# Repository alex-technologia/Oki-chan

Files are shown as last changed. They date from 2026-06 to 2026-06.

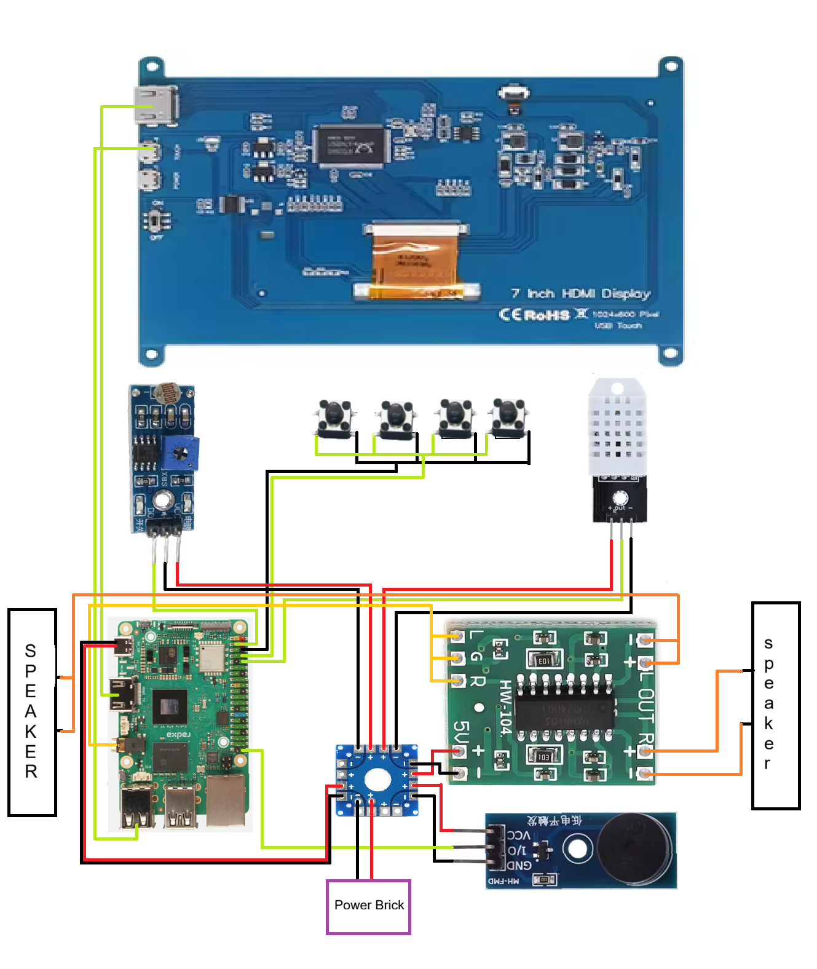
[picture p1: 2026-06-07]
Schematics/Wiring schematic.png

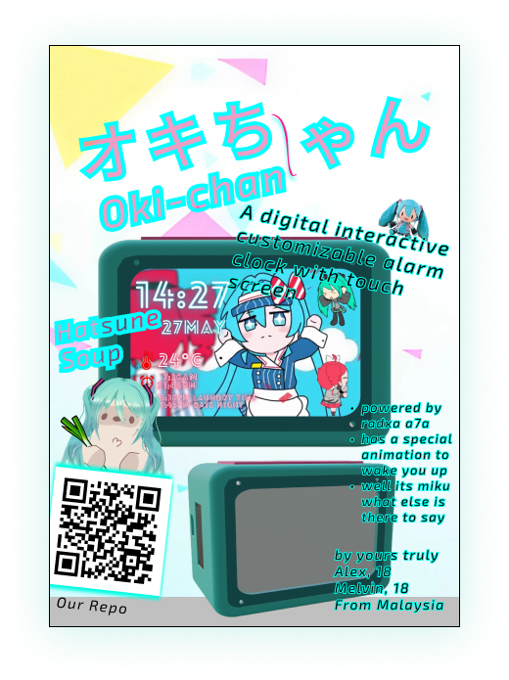
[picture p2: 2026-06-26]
assets/Okichan Zine.png

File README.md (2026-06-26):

<p align="center">
  
</p>

<table>
<tr>
<td width="40%">

Okichan Zine

</td>

<td width="60%">

<h3>Oki-chan (Okiru = wake up / Ooki = big)</h3>

A digital interactive customizable alarm clock with a touch screen. Normal alarm clocks are boring—animate whatever you want and put it on the display. I'm probably going to use an anime character, but it's completely customizable on the software side.

This alarm clock runs Linux/Android, so you can run almost anything you want on it—even Doom.

We created software that functions as both an alarm clock and a character display. The default character is
giphy,
but you can replace it with whoever you like. (work in progress)

We made this project to prove that waking up doesn't have to be frustrating or painful while still giving users complete freedom to customize their experience. ps. I hate waking up so I'm trying to make waking up fun!

It is super simple to use, just install the android firmware from radxa's official website and you're ready to go! It's touchscreen so u can use it like any mobile gadget but in the form of an alarm clock.

</td>
</tr>
</table>

## Onshape link 
[[https://cad.onshape.com/documents/88c036c3c5f450a3cafc0f79/w/50fab2545bc89d9e2dabb88b/e/1d1f4fe3c64da217baa0164f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](https://cad.onshape.com/documents/4e082104674894d5913c4831/w/89eadd96b42d6e928645da0e/e/e63404fe947eb1d5f2b5a918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)](https://cad.onshape.com/documents/c2196d859270cbefb2446175/w/1e22324b9374e77f752ec0d0/e/32ebcde7a799d4cd3d4bf5ae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)

## 3D Model
  <tr>
    <td>
      
    </td>
    <td>
      
    </td>
  </tr>
  <tr>
    <td>
      
    </td>
    <td>
      
    </td>
  </tr>
</table>

## Wiring Diagram
Wiring schematic

🟥RED = +wire
⬛BLACK = -wire
🟩GREEN = Data wire
🟧ORANGE = Audio+/-
🟨YELLOW = AUX Wire

## BOM


## Flashing Firmware
Android
Compatible with microSD cards, eMMC modules, and UFS modules.

<table>
  <tr>
    <td colspan="2">

## 1. Download Firmware

### Radxa Cubie A7A Android 13 Images

[Radxa Cubie A7A Android 13 **20250814**](https://github.com/radxa/allwinner-android-manifests/releases/download/A733-Android13-20250814/a733_android13_radxa_a7a_20250814_uart0.zip): for Cubie A7A with **AC101** audio codec

[Radxa Cubie A7A Android 13 **20260206**](https://github.com/radxa/allwinner-android-manifests/releases/download/A733-Android13-20260205/a733_android13_radxa_a7a_20260206_uart0.zip): for Cubie A7A with **AC101B** audio codec

  </tr>

  <tr>
    <td width="50%" valign="top">

## 2A. SD Card Flashing

### SD Card Boot Disk Creation Tool

- [PhoenixCard V4.3.2](https://dl.radxa.com/tools/windows/PhoenixCard_V4.3.2_20250331_1604_Release.zip)

1. Insert SD card into PC.
2. Open PhoenixCard.
3. Select the firmware image from Step 1.
4. Create the bootable SD card.
5. Insert SD card into the Radxa A7A and power on.

    </td>

    <td width="50%" valign="top">

## 2B. USB Flashing

### System Flashing Tools

- [PhoenixSuit](https://dl.radxa.com/tools/windows/PhoenixSuit_V2.0.4.zip) (Windows)
- [LiveSuit](https://dl.radxa.com/tools/linux/LiveSuit_Linux_V3.0.8.zip) (Linux)

1. Unplug power and USB cables from the Radxa A7A.
2. Press and hold the **UBOOT** button.
3. Connect the Radxa A7A to the PC using a USB cable.
4. Release the **UBOOT** button.
5. Open Device Manager and verify the board appears under USB Devices.
6. Open PhoenixSuit/LiveSuit and select the firmware image from Step 1.
7. Choose **Full Flash**.
8. Wait until **"Firmware flashed successfully"** is displayed.
9. The board is now ready to use.
  </tr>
</table>

Official Radxa A7a Android Docs [HERE](https://docs.radxa.com/en/cubie/a7a/other-system/android) 

(Debian&Tina not used in this project), it's available by following [Radxa official docs](https://docs.radxa.com/en/cubie/a7a/download) if you want.

## **Apps**
Oki-chan is not limited by our app, thus you can use any other app you want that is android (side-loading required).

As for our app, it will be running as [Oki-chan Webui.html]() file and is still in devolopment. 

## Preview
What could be possible (we haven't made the software for it yet)  

https://github.com/user-attachments/assets/e6b8e22e-ab00-47f7-8dbc-2a04c18cb579

## Zine 
Untitled(22)

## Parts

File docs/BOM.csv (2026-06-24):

Item | Purpose | Source | Price (Malaysia Currency) | Price (usd) | Quantity | Link
Radxa cubie a7a | Main computer | Aliexpress | 153 | 38.62 | 1 | https://www.aliexpress.com/item/1005009735747676.html
Micro Digital Amplier Board | For the audio amplifier speaker | Aliexpress | 2.09 | 0.53 | 1 | https://a.aliexpress.com/_c3usjmxJ
Audio amplifier board plastic speaker | As the speaker for the alarm | TaoBao | 2.90 | 0.73 | 2 | https://click.world.taobao.com/_b.bbuoO7
Passive Buzzer Module | As the vibration module for the alarm vibration | Aliexpress | 4.00 | 1.01 | 1 | https://www.aliexpress.com/item/1005010218492946.html
Screen With Touch Film (7 inch) | As the screen that shows the animation | TaoBao | 106.79 | 26.95 | 1 | https://click.world.taobao.com/_b.hbuo7h
Tactile switch button | As the snooze button | TaoBao | 1.53 | 0.39 | 4 | https://click.world.taobao.com/_b.4bupYW
Power Supply Adapter 5V 6A | Changes alternating current to direct current | Aliexpress | 21.58 | 5.45 | 1 | https://www.aliexpress.com/item/1005005622817698.html
Power Distribution Board | Distribute the current to other parts | Aliexpress | 17.94 | 4.53 | 1 | https://www.aliexpress.com/item/1005001835785033.html
M4 and M2.5 hex screws | Hold components together | Alixpress | ±10 | ±2.53 | 31 | https://www.aliexpress.com/item/1005006904738286.html
Wires | Allow current to be transferred to the parts | Owned | ±2.00 | ±0.50 | - | -
3D Printer | Used to print out the model | Owned | - | - | - | -
3D Printer FIlament PLA+ | Filament for 3D printer | owned | ±30.00 | ±7.24 | - | -
Solder | Used to solder wire and electronic components together | owned | - | - | - | -
Soldering stick | Used to melt solder | owned | ±10.00 | ±2.41 | - | -
TOTAL COST | - | (Not including things we owned) | ±320.31 | ±77.29 | - | -

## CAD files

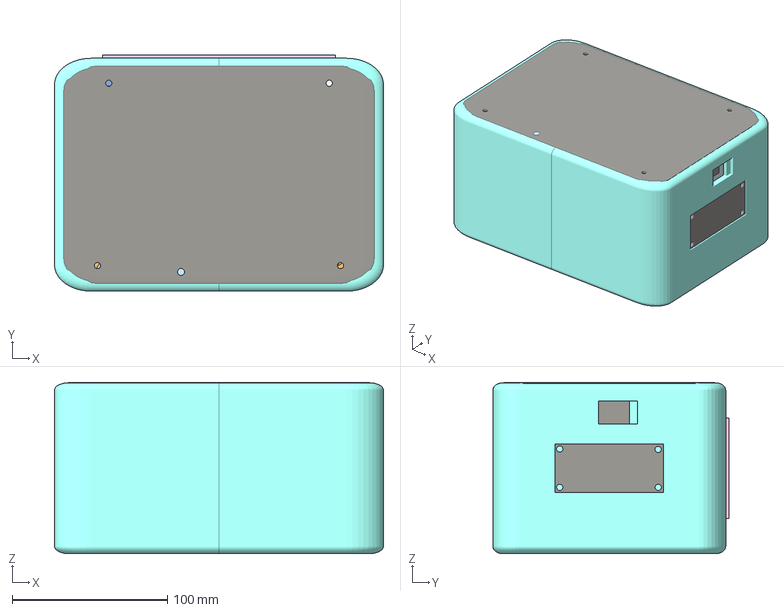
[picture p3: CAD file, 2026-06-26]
Schematics/okichanv5(1).step
211.8 x 152.2 x 110.3 mm

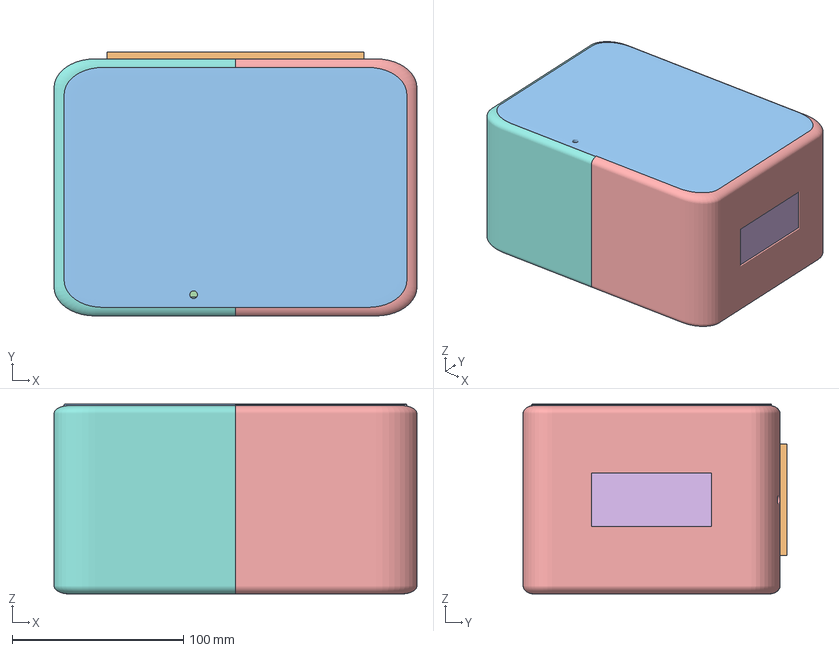
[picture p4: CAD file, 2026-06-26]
Schematics/oki.FCStd
211.8 x 154.0 x 110.9 mm
switch.004 (1)
speaker.001 (1)
buck converter holder
speaker.001
vibrator holder bottom
back cover holder
Case.002 (3)
light sensor
back cover holder (4)
Case.002 (7)
switch (1)
back cover holder (2)
Case.002 (4)
switch
back cover holder (1)
Case.002
switch.001 (1)
sbc holder.002
Case.002 (5)
switch.001
amp holder top (7)
switch.003 (1)
amp holder bottom
amp holder top (1)
back cover holder (3)
Case.002 (1)
sbc
switch.003
switch.004
amp holder top (6)
buck converter
Case.002 (6)
screen (1)
amp holder top (2)
amp holder top
switch.002
Case.002 (2)
sbc holder.001
amp holder top (4)
switch.002 (1)
screen
sbc holder
speaker (1)
amp holder top (5)
screen holder (4)
PDB
speaker
amp holder top (3)
screen holder
powerjack
vibrator holder top
Case.002 (6)001
screen holder (3)
screen holder (1)
screen holder (2)

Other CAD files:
Schematics/okichanv5 renderv7 .blend
Schematics/okichanv5.blend
docs/3D Model.blend

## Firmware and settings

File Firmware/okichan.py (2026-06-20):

import os
import sys
import time
import threading
import subprocess
import webview

# Attempt to load native Linux I/O drivers
try:
    import gpiod
    HARDWARE_AVAILABLE = True
except ImportError:
    HARDWARE_AVAILABLE = False
    print("[WARN] gpiod library missing. Initializing in desktop emulation mode.")

# ==========================================
# HARDWARE CORE PIN CONFIGURATION
# ==========================================
GPIO_CHIP_NAME = "gpiochip4"
PIN_BUTTON_1 = 10   # Cycle App Pages
PIN_BUTTON_2 = 11   # Trigger Buzzer Pulse
PIN_BUTTON_3 = 12   # System Volume Up
PIN_BUTTON_4 = 13   # System Volume Down
PIN_LIGHT_IN = 14   # Digital Input from Photoresistor Module
PIN_BUZZER_OUT = 15 # Digital Output to Piezo Buzzer

SOUND_FILE_PATH = "/usr/share/sounds/alsa/Front_Center.wav"

class WebAppHardwareBridge:
    """API Object exposed directly to JavaScript inside the WebView window container."""
    def __init__(self):
        self.window = None
        self.volume_level = 70
        self.running = True
        self.init_gpio_lines()

    def init_gpio_lines(self):
        if not HARDWARE_AVAILABLE:
            return
        try:
            self.chip = gpiod.Chip(GPIO_CHIP_NAME)
            
            # Map out hardware inputs with active-low safety bounds
            self.btn1 = self.chip.get_line(PIN_BUTTON_1); self.btn1.request(consumer="WebHub", type=gpiod.LINE_REQ_DIR_IN)
            self.btn2 = self.chip.get_line(PIN_BUTTON_2); self.btn2.request(consumer="WebHub", type=gpiod.LINE_REQ_DIR_IN)
            self.btn3 = self.chip.get_line(PIN_BUTTON_3); self.btn3.request(consumer="WebHub", type=gpiod.LINE_REQ_DIR_IN)
            self.btn4 = self.chip.get_line(PIN_BUTTON_4); self.btn4.request(consumer="WebHub", type=gpiod.LINE_REQ_DIR_IN)
            self.light_sensor = self.chip.get_line(PIN_LIGHT_IN); self.light_sensor.request(consumer="WebHub", type=gpiod.LINE_REQ_DIR_IN)
            
            # Map out output lines
            self.buzzer = self.chip.get_line(PIN_BUZZER_OUT); self.buzzer.request(consumer="WebHub", type=gpiod.LINE_REQ_DIR_OUT, default_vals=[0])
        except Exception as err:
            print(f"[GPIO Initialization Failure]: {err}")

    # --- Methods triggered directly from user interface clicks inside the Web UI ---
    def play_audio_alert(self):
        """Fired when UI Audio buttons are clicked."""
        if os.path.exists(SOUND_FILE_PATH):
            subprocess.run(["aplay", SOUND_FILE_PATH], stdout=subprocess.DEVNULL, stderr=subprocess.DEVNULL)
        return {"status": "success"}

    def pulse_hardware_buzzer(self):
        """Fired when UI Test Buzzer buttons are clicked."""
        def run_pulse():
            if HARDWARE_AVAILABLE:
                self.buzzer.set_value(1)
                time.sleep(0.15)
                self.buzzer.set_value(0)
            else:
                print("[EMULATION] *Buzzer Beep*")
        threading.Thread(target=run_pulse, daemon=True).start()
        return {"status": "activated"}

    def change_system_volume(self, target_direction):
        if target_direction == "up" and self.volume_level < 100:
            self.volume_level += 5
        elif target_direction == "down" and self.volume_level > 0:
            self.volume_level -= 5
        subprocess.run(["amixer", "sset", "Master", f"{self.volume_level}%"], stdout=subprocess.DEVNULL, stderr=subprocess.DEVNULL)
        return self.volume_level

    # --- Background Loop pushing data back into the Web DOM ---
    def start_hardware_polling(self):
        """Monitors input lines and executes javascript strings inside the runtime window context."""
        current_page_idx = 0
        pages_list = ["page-main-hub", "page-alarms", "page-tasks"]
        dht_ticks = 0

        while self.running:
            if HARDWARE_AVAILABLE:
                try:
                    # 1. Hardware Buttons mapped directly to Application Navigation Events
                    if self.btn1.get_value() == 0:  # Page Cycle Switch Button
                        current_page_idx = (current_page_idx + 1) % len(pages_list)
                        self.window.evaluate_js(f"switchPage('{pages_list[current_page_idx]}')")
                        time.sleep(0.3)

                    if self.btn2.get_value() == 0:  # Physical Trigger for the Buzzer
                        self.pulse_hardware_buzzer()
                        time.sleep(0.3)

                    if self.btn3.get_value() == 0:  # Volume Up Pin
                        self.change_system_volume("up")
                        time.sleep(0.15)

                    if self.btn4.get_value() == 0:  # Volume Down Pin
                        self.change_system_volume("down")
                        time.sleep(0.15)

                    # 2. Update Webpage UI based on Photoresistor state
                    # Automatically dismisses screensaver overlay if light status changes significantly
                    if self.light_sensor.get_value() == 0:
                        self.window.evaluate_js("userActivityRegistered();")

                    # 3. Read Temp/Humidity Data from SysFS nodes into Web Screensaver View
                    dht_ticks += 1
                    if dht_ticks >= 20: # Query hardware roughly every 2 seconds
                        temp_path = "/sys/bus/iio/devices/iio:device0/in_temp_input"
                        if os.path.exists(temp_path):
                            with open(temp_path, "r") as f:
                                current_temp = float(f.read().strip()) / 1000.0
                            # Dynamically modifies the target text node within the screensaver stack layout
                            js_update = f"document.querySelector('#idle-screensaver .saver-widget-row span').textContent = '{current_temp:.1f}°C';"
                            self.window.evaluate_js(js_update)
                        dht_ticks = 0

                except Exception as loop_error:
                    print(f"Polling loop hiccup: {loop_error}")

            time.sleep(0.1)

    def cleanup(self):
        self.running = False
        if HARDWARE_AVAILABLE:
            try:
                for line in [self.btn1, self.btn2, self.btn3, self.btn4, self.light_sensor, self.buzzer]:
                    line.release()
            except:
                pass

if __name__ == "__main__":
    bridge = AppHardwareBridge()
    
    # Establish full view window matching your 7-inch display dimensions
    window = webview.create_window(
        title="Smart Task Multi-Hub",
        url="Oki-chan Webui.html",
        js_api=bridge,
        fullscreen=True, # Launches app borderless covering window environment elements
        background_color="#0c0f12"
    )
    
    bridge.window = window
    
    # Fire off background hardware monitor loop right as the Web View engine stabilizes
    window.events.loaded += lambda: threading.Thread(target=bridge.start_hardware_polling, daemon=True).start()
    
    webview.start()
    bridge.cleanup()

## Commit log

2026-05-02 Wiring diagram
2026-05-03 Update README with images for CAD and Wiring Diagram
    Added images for CAD, Wiring Diagram sections.
2026-05-03 Added the Oki-chan blender model
    [okichanv2.blend]
2026-06-07 Rename okichanv2.blend to 3D Model.blend
    [3D Model.blend]
2026-06-07 Rename Wiring schematic.png to docs/Wiring schematic.png
2026-06-07 Rename 3D Model.blend to docs/3D Model.blend
    [3D Model.blend]
2026-06-07 Rename docs/3D Model.blend to 3D Model.blend
    [3D Model.blend]
2026-06-07 Rename docs/Wiring schematic.png to Wiring schematic.png
2026-06-15 Rename 3D Model.blend to Schematics/3D Model.blend
    [3D Model.blend]
2026-06-15 Rename Wiring schematic.png to Schematics/Wiring schematic.png
